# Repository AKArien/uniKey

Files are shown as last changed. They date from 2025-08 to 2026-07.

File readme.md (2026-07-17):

# Unikey

I think this name is corny as hell, but i needed one, sooo

Very unhappy with the way keyboards are currently handled (i’ll write my manifesto one day and i’ll link it here), this is my custom keyboard’s firmware, using the HID unicode page. It contains firmware source code and files i use to make the hardware, as well as examples to make your own.

# Hacking

If you want to change the layout for the unicode mode, check out src/key/unicode.h

If you want to tweak and re-use the usb reports, check out src/descriptors.h.

If you want a « classic » keyboard with one of the microcontrollers / physical builds (see below), you can change the code to force the mode and re-use it from there.

If you want a « classic » keyboard with another microncontroller / physical build, check out project [Golem](https://golem.hu/) and [QMK](https://github.com/qmk/qmk_firmware).

# Hardware

There is currently one physical keyboard in the project, though i do plan on making more.
The names used below are the ones needed for compilation of the firmware with them. Check firmware section for more details.

ALL_MAINBOARD :
- Physical configuration :
  - Ortholinear, 266\*95mm
  - Split, 2\*2,5-wide bottom-row keys « spacebar », 2-tall rightmost key « enter/return »
  - 5\*14,
- Available schematics use :
  - An arduino pro mini
  - 66 keys and as many diodes
  - Resistors and zener diodes for V-USB
- Features (almost) all the keys needed to make a classic keyboard, including « pinky keys » and arrow keys.
  - Lacks function keys, though you could probably easily add them to the topmost row (the keys that usually have numbers) with a modifier, or straight up adding a row of keys.
  - Doesn’t have space for both an escape and another key on the left of the topmost row (though most users probably wouldn’t even notice)
  - Assuming standard placement of return, backslash and modifiers, there is not really space for a classicly positioned « delete next » key. You could rather easily modify the pcb to make the « enter » key 1\*1, freeing space for another key and placing your deleting keys as you wish. The default is to have « delete previous » in the split long key on the bottom row and « delete next » in the top right corner.

# Firmware

The goal of the project is to make a keyboard that uses the Unicode HID page (0x10) for the host OS to use firmware-decided characters. In other words, a *really* plug and play keyboard.

As mentionned in hardware section, this repository will likely eventually have more keyboards. For now, only one exists.

Compilation of the firmware for the different models is scheduled to be handled with preprocessor flags passed to the makefile. So, to compile for the model ALL_MAINBOARD, you would use : ```make MODEL=ALL_MAINBOARD```

The ALL_MAINBOARD design uses the V-USB library, as it doesn’t have a dedicated USB chip.

To upload, use ```make upload ISP=<your in-circuit serial programmer, as per avrdude>```

Tip : UNOs can serve as in-cuircuit programmers ! They are named `arduino` to avrdude. Check out :
- Wiring and explanations : https://docs.arduino.cc/built-in-examples/arduino-isp/ArduinoISP/
- Arduino sketch : https://gist.github.com/srmq/0217a2844a9d82a6913ff989472a98dd

# Thanks

Obdev, for making V-USB

Sine Lab’s V-USB keyboard sample project, from which most of the code to use v-usb comes https://www.youtube.com/watch?v=6U_bHTnFu-g

The Kicad community, for making such good software and resources

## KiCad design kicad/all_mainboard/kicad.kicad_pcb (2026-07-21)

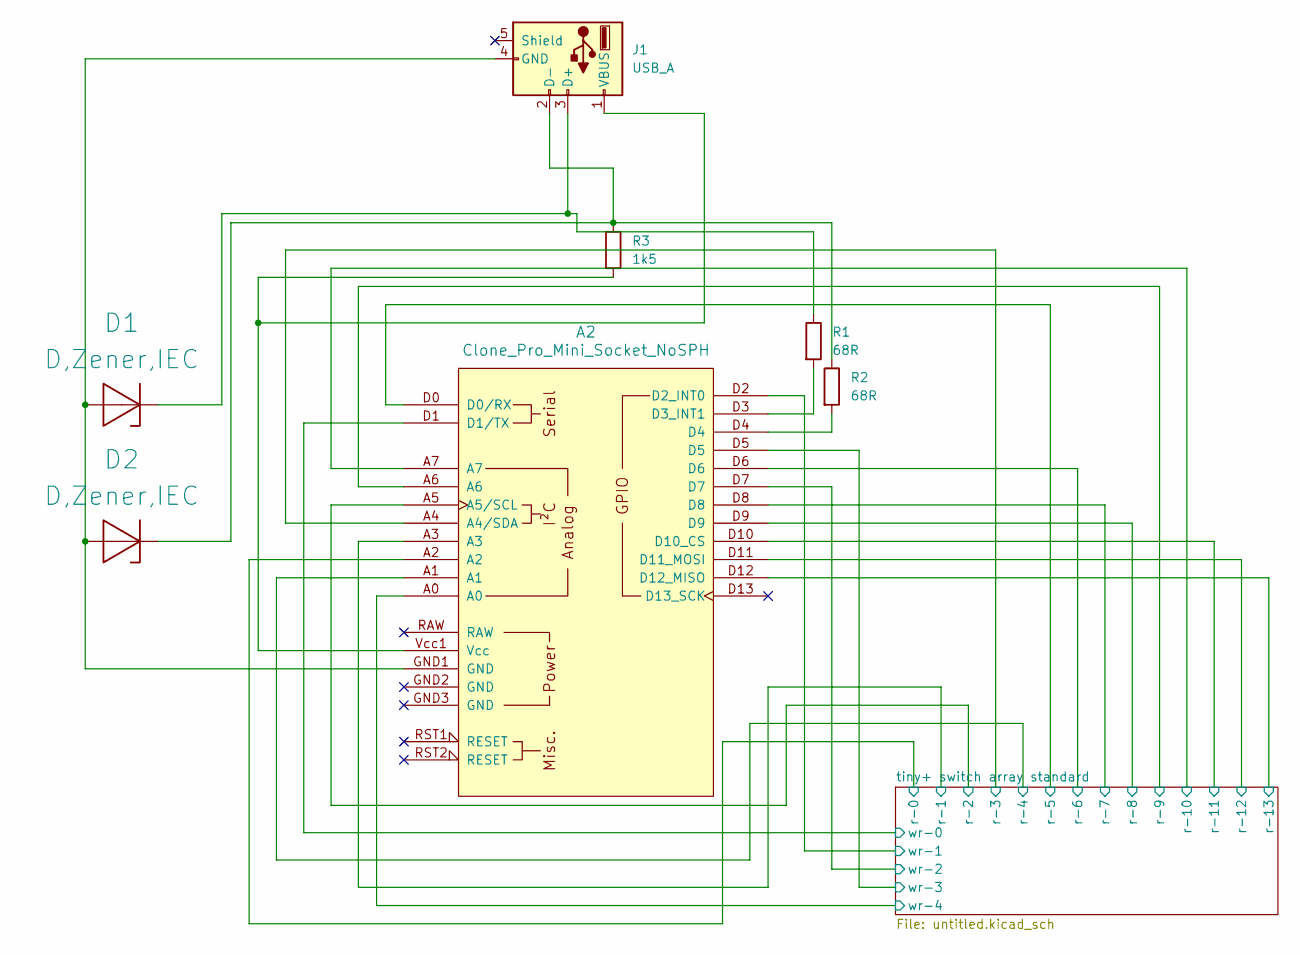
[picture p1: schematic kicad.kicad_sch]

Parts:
A2: Clone_Pro_Mini_Socket_NoSPH
D1, D2: D,Zener,IEC; D_DO-41_SOD81_P10.16mm_Horizontal
J1: USB_A; PinHeader_1x04_P2.00mm_Horizontal
R1, R2: 68R; D_DO-41_SOD81_P10.16mm_Horizontal
R3: 1k5; D_DO-41_SOD81_P10.16mm_Horizontal

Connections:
/tiny+ switch array standard/r-0: A2.A2; also elsewhere on the board
/tiny+ switch array standard/r-1: A2.A3; also elsewhere on the board
/tiny+ switch array standard/r-2: A2.A5 (A5/SCL); also elsewhere on the board
/tiny+ switch array standard/r-3: A2.A4 (A4/SDA); also elsewhere on the board
/tiny+ switch array standard/r-4: A2.A1; also elsewhere on the board
/tiny+ switch array standard/r-5: A2.D0 (D0/RX); also elsewhere on the board
/tiny+ switch array standard/r-6: A2.D6; also elsewhere on the board
/tiny+ switch array standard/r-7: A2.D8; also elsewhere on the board
/tiny+ switch array standard/r-8: A2.D9; also elsewhere on the board
/tiny+ switch array standard/r-9: A2.A6; also elsewhere on the board
/tiny+ switch array standard/r-10: A2.A7; also elsewhere on the board
/tiny+ switch array standard/r-11: A2.D10 (D10_CS); also elsewhere on the board
/tiny+ switch array standard/r-12: A2.D11 (D11_MOSI); also elsewhere on the board
/tiny+ switch array standard/r-13: A2.D12 (D12_MISO); also elsewhere on the board
/tiny+ switch array standard/wr-0: A2.D1 (D1/TX); also elsewhere on the board
/tiny+ switch array standard/wr-1: A2.D2 (D2_INT0); also elsewhere on the board
/tiny+ switch array standard/wr-2: A2.D7; also elsewhere on the board
/tiny+ switch array standard/wr-3: A2.D5; also elsewhere on the board
/tiny+ switch array standard/wr-4: A2.A0; also elsewhere on the board
unnamed: A2.D3 (D3_INT1), R1.2
unnamed: A2.D4, R2.2
unnamed: A2.Vcc1 (Vcc), J1.1 (VBUS), R3.2
unnamed: A2.GND1 (GND), D1.2 (A+), D2.2 (A+), J1.4 (GND)
unnamed: D1.1 (K-), J1.3 (D+), R1.1
unnamed: D2.1 (K-), J1.2 (D-), R2.1, R3.1

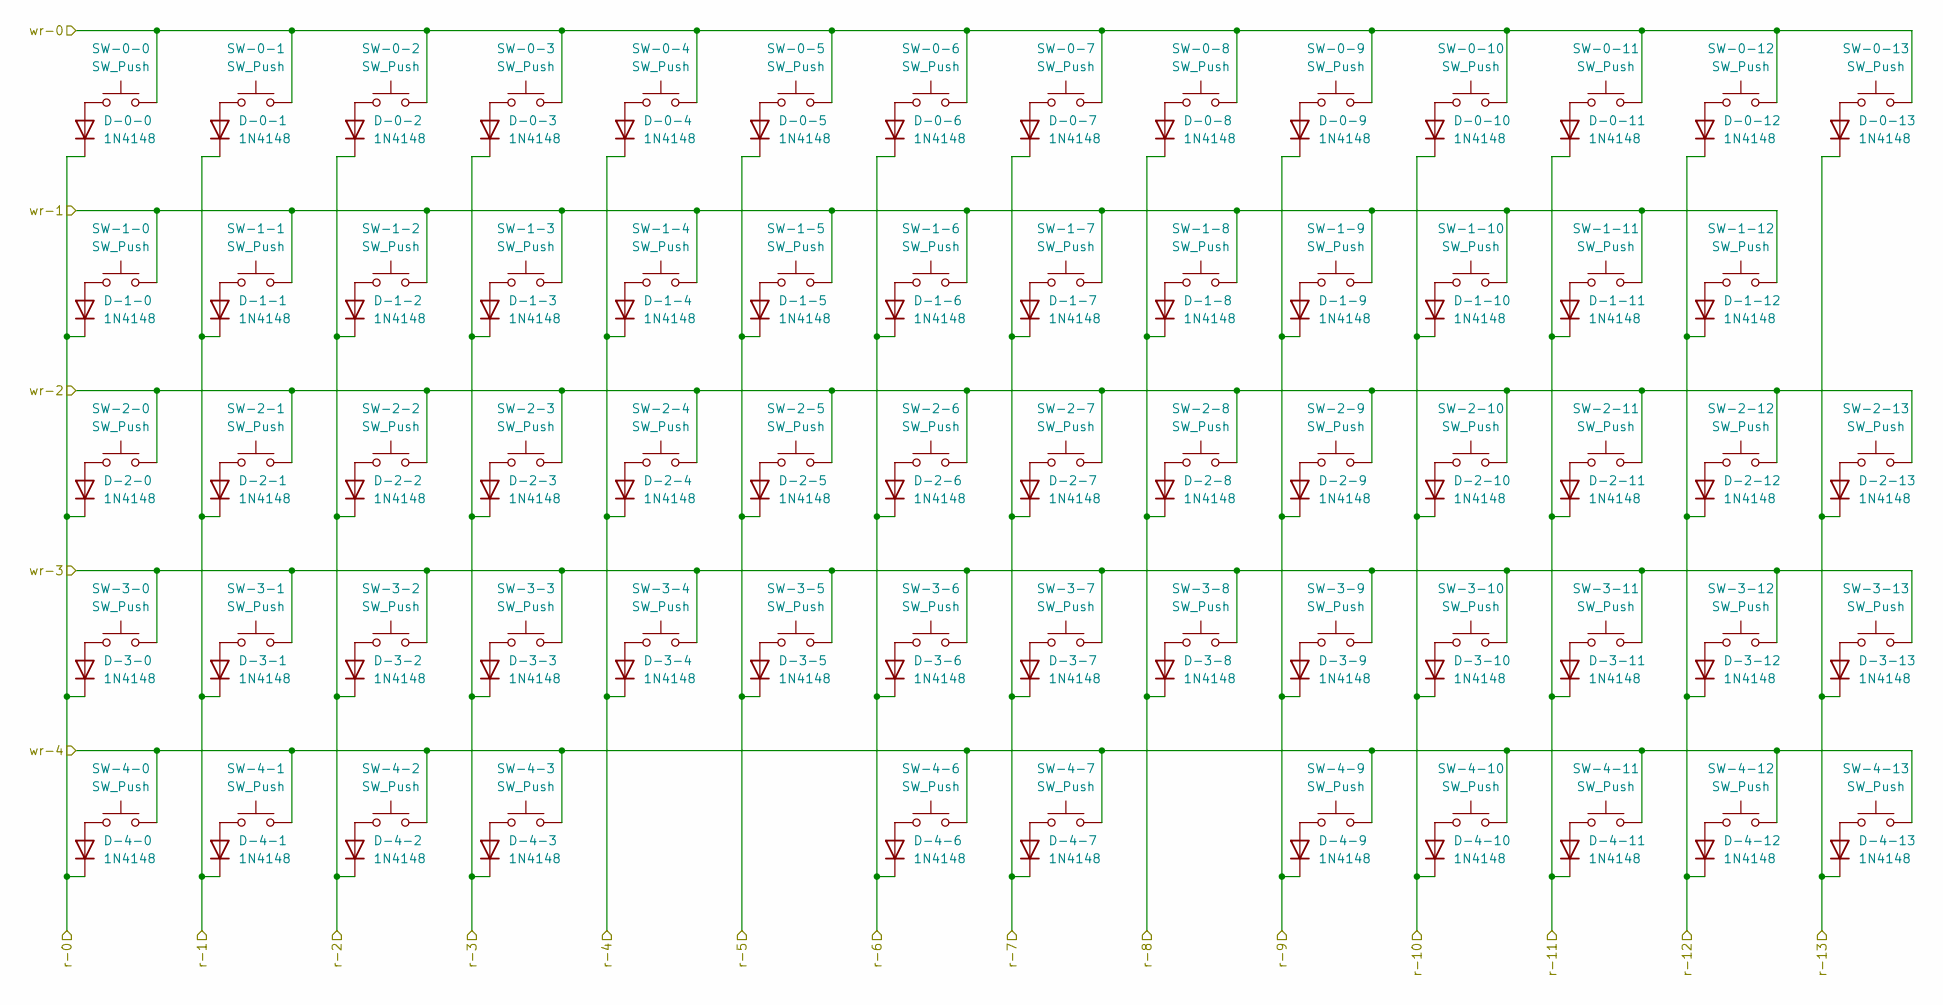
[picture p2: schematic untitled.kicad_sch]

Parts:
D-0-0, D-0-1, D-0-2, D-0-3, D-0-4, D-0-5, D-0-6, D-0-7, D-0-8, D-0-9, D-0-10, D-0-11, D-0-12, D-0-13, D-1-0, D-1-1, D-1-2, D-1-3, D-1-4, D-1-5, D-1-6, D-1-7, D-1-8, D-1-9, D-1-10, D-1-11, D-1-12, D-2-0, D-2-1, D-2-2, D-2-3, D-2-4, D-2-5, D-2-6, D-2-7, D-2-8, D-2-9, D-2-10, D-2-11, D-2-12, D-2-13, D-3-0, D-3-1, D-3-2, D-3-3, D-3-4, D-3-5, D-3-6, D-3-7, D-3-8, D-3-9, D-3-10, D-3-11, D-3-12, D-3-13, D-4-0, D-4-1, D-4-2, D-4-3, D-4-6, D-4-7, D-4-9, D-4-10, D-4-11, D-4-12, D-4-13: 1N4148; D_DO-35_SOD27_P7.62mm_Horizontal
SW-0-0, SW-0-1, SW-0-2, SW-0-3, SW-0-4, SW-0-5, SW-0-6, SW-0-7, SW-0-8, SW-0-9, SW-0-10, SW-0-11, SW-0-12, SW-0-13, SW-1-0, SW-1-1, SW-1-2, SW-1-3, SW-1-4, SW-1-5, SW-1-6, SW-1-7, SW-1-8, SW-1-9, SW-1-10, SW-1-11, SW-1-12, SW-2-0, SW-2-1, SW-2-2, SW-2-3, SW-2-4, SW-2-5, SW-2-6, SW-2-7, SW-2-8, SW-2-9, SW-2-10, SW-2-11, SW-2-12, SW-2-13, SW-3-0, SW-3-1, SW-3-2, SW-3-3, SW-3-4, SW-3-5, SW-3-6, SW-3-7, SW-3-8, SW-3-9, SW-3-10, SW-3-11, SW-3-12, SW-3-13, SW-4-0, SW-4-1, SW-4-2, SW-4-3, SW-4-6, SW-4-7, SW-4-9, SW-4-10, SW-4-11, SW-4-12, SW-4-13: SW_Push; SW_Cherry_MX_1.00u_PCB

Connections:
/tiny+ switch array standard/r-0: D-0-0.1 (K), D-1-0.1 (K), D-2-0.1 (K), D-3-0.1 (K), D-4-0.1 (K); also elsewhere on the board
/tiny+ switch array standard/r-1: D-0-1.1 (K), D-1-1.1 (K), D-2-1.1 (K), D-3-1.1 (K), D-4-1.1 (K); also elsewhere on the board
/tiny+ switch array standard/r-2: D-0-2.1 (K), D-1-2.1 (K), D-2-2.1 (K), D-3-2.1 (K), D-4-2.1 (K); also elsewhere on the board
/tiny+ switch array standard/r-3: D-0-3.1 (K), D-1-3.1 (K), D-2-3.1 (K), D-3-3.1 (K), D-4-3.1 (K); also elsewhere on the board
/tiny+ switch array standard/r-4: D-0-4.1 (K), D-1-4.1 (K), D-2-4.1 (K), D-3-4.1 (K); also elsewhere on the board
/tiny+ switch array standard/r-5: D-0-5.1 (K), D-1-5.1 (K), D-2-5.1 (K), D-3-5.1 (K); also elsewhere on the board
/tiny+ switch array standard/r-6: D-0-6.1 (K), D-1-6.1 (K), D-2-6.1 (K), D-3-6.1 (K), D-4-6.1 (K); also elsewhere on the board
/tiny+ switch array standard/r-7: D-0-7.1 (K), D-1-7.1 (K), D-2-7.1 (K), D-3-7.1 (K), D-4-7.1 (K); also elsewhere on the board
/tiny+ switch array standard/r-8: D-0-8.1 (K), D-1-8.1 (K), D-2-8.1 (K), D-3-8.1 (K); also elsewhere on the board
/tiny+ switch array standard/r-9: D-0-9.1 (K), D-1-9.1 (K), D-2-9.1 (K), D-3-9.1 (K), D-4-9.1 (K); also elsewhere on the board
/tiny+ switch array standard/r-10: D-0-10.1 (K), D-1-10.1 (K), D-2-10.1 (K), D-3-10.1 (K), D-4-10.1 (K); also elsewhere on the board
/tiny+ switch array standard/r-11: D-0-11.1 (K), D-1-11.1 (K), D-2-11.1 (K), D-3-11.1 (K), D-4-11.1 (K); also elsewhere on the board
/tiny+ switch array standard/r-12: D-0-12.1 (K), D-1-12.1 (K), D-2-12.1 (K), D-3-12.1 (K), D-4-12.1 (K); also elsewhere on the board
/tiny+ switch array standard/r-13: D-0-13.1 (K), D-2-13.1 (K), D-3-13.1 (K), D-4-13.1 (K); also elsewhere on the board
/tiny+ switch array standard/wr-0: SW-0-0.2, SW-0-1.2, SW-0-2.2, SW-0-3.2, SW-0-4.2, SW-0-5.2, SW-0-6.2, SW-0-7.2, SW-0-8.2, SW-0-9.2, SW-0-10.2, SW-0-11.2, SW-0-12.2, SW-0-13.2; also elsewhere on the board
/tiny+ switch array standard/wr-1: SW-1-0.2, SW-1-1.2, SW-1-2.2, SW-1-3.2, SW-1-4.2, SW-1-5.2, SW-1-6.2, SW-1-7.2, SW-1-8.2, SW-1-9.2, SW-1-10.2, SW-1-11.2, SW-1-12.2; also elsewhere on the board
/tiny+ switch array standard/wr-2: SW-2-0.2, SW-2-1.2, SW-2-2.2, SW-2-3.2, SW-2-4.2, SW-2-5.2, SW-2-6.2, SW-2-7.2, SW-2-8.2, SW-2-9.2, SW-2-10.2, SW-2-11.2, SW-2-12.2, SW-2-13.2; also elsewhere on the board
/tiny+ switch array standard/wr-3: SW-3-0.2, SW-3-1.2, SW-3-2.2, SW-3-3.2, SW-3-4.2, SW-3-5.2, SW-3-6.2, SW-3-7.2, SW-3-8.2, SW-3-9.2, SW-3-10.2, SW-3-11.2, SW-3-12.2, SW-3-13.2; also elsewhere on the board
/tiny+ switch array standard/wr-4: SW-4-0.2, SW-4-1.2, SW-4-2.2, SW-4-3.2, SW-4-6.2, SW-4-7.2, SW-4-9.2, SW-4-10.2, SW-4-11.2, SW-4-12.2, SW-4-13.2; also elsewhere on the board
unnamed: D-0-0.2 (A), SW-0-0.1
unnamed: D-0-1.2 (A), SW-0-1.1
unnamed: D-0-2.2 (A), SW-0-2.1
unnamed: D-0-3.2 (A), SW-0-3.1
unnamed: D-0-4.2 (A), SW-0-4.1
unnamed: D-0-5.2 (A), SW-0-5.1
unnamed: D-0-6.2 (A), SW-0-6.1
unnamed: D-0-7.2 (A), SW-0-7.1
unnamed: D-0-8.2 (A), SW-0-8.1
unnamed: D-0-9.2 (A), SW-0-9.1
unnamed: D-0-10.2 (A), SW-0-10.1
unnamed: D-0-11.2 (A), SW-0-11.1
unnamed: D-0-12.2 (A), SW-0-12.1
unnamed: D-0-13.2 (A), SW-0-13.1
unnamed: D-1-0.2 (A), SW-1-0.1
unnamed: D-1-1.2 (A), SW-1-1.1
unnamed: D-1-2.2 (A), SW-1-2.1
unnamed: D-1-3.2 (A), SW-1-3.1
unnamed: D-1-4.2 (A), SW-1-4.1
unnamed: D-1-5.2 (A), SW-1-5.1
unnamed: D-1-6.2 (A), SW-1-6.1
unnamed: D-1-7.2 (A), SW-1-7.1
unnamed: D-1-8.2 (A), SW-1-8.1
unnamed: D-1-9.2 (A), SW-1-9.1
unnamed: D-1-10.2 (A), SW-1-10.1
unnamed: D-1-11.2 (A), SW-1-11.1
unnamed: D-1-12.2 (A), SW-1-12.1
unnamed: D-2-0.2 (A), SW-2-0.1
unnamed: D-2-1.2 (A), SW-2-1.1
unnamed: D-2-2.2 (A), SW-2-2.1
unnamed: D-2-3.2 (A), SW-2-3.1
unnamed: D-2-4.2 (A), SW-2-4.1
unnamed: D-2-5.2 (A), SW-2-5.1
unnamed: D-2-6.2 (A), SW-2-6.1
unnamed: D-2-7.2 (A), SW-2-7.1
unnamed: D-2-8.2 (A), SW-2-8.1
unnamed: D-2-9.2 (A), SW-2-9.1
unnamed: D-2-10.2 (A), SW-2-10.1
unnamed: D-2-11.2 (A), SW-2-11.1
unnamed: D-2-12.2 (A), SW-2-12.1
unnamed: D-2-13.2 (A), SW-2-13.1
unnamed: D-3-0.2 (A), SW-3-0.1
unnamed: D-3-1.2 (A), SW-3-1.1
unnamed: D-3-2.2 (A), SW-3-2.1
unnamed: D-3-3.2 (A), SW-3-3.1
unnamed: D-3-4.2 (A), SW-3-4.1
unnamed: D-3-5.2 (A), SW-3-5.1
unnamed: D-3-6.2 (A), SW-3-6.1
unnamed: D-3-7.2 (A), SW-3-7.1
unnamed: D-3-8.2 (A), SW-3-8.1
unnamed: D-3-9.2 (A), SW-3-9.1
unnamed: D-3-10.2 (A), SW-3-10.1
unnamed: D-3-11.2 (A), SW-3-11.1
unnamed: D-3-12.2 (A), SW-3-12.1
unnamed: D-3-13.2 (A), SW-3-13.1
unnamed: D-4-0.2 (A), SW-4-0.1
unnamed: D-4-1.2 (A), SW-4-1.1
unnamed: D-4-2.2 (A), SW-4-2.1
unnamed: D-4-3.2 (A), SW-4-3.1
unnamed: D-4-6.2 (A), SW-4-6.1
unnamed: D-4-7.2 (A), SW-4-7.1
unnamed: D-4-9.2 (A), SW-4-9.1
unnamed: D-4-10.2 (A), SW-4-10.1
unnamed: D-4-11.2 (A), SW-4-11.1
unnamed: D-4-12.2 (A), SW-4-12.1
unnamed: D-4-13.2 (A), SW-4-13.1

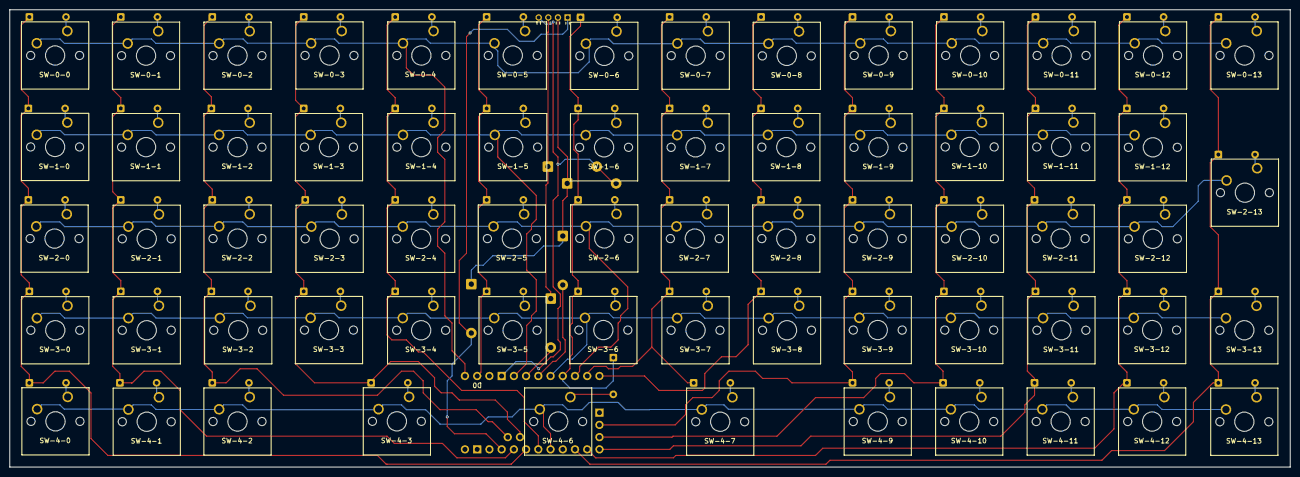
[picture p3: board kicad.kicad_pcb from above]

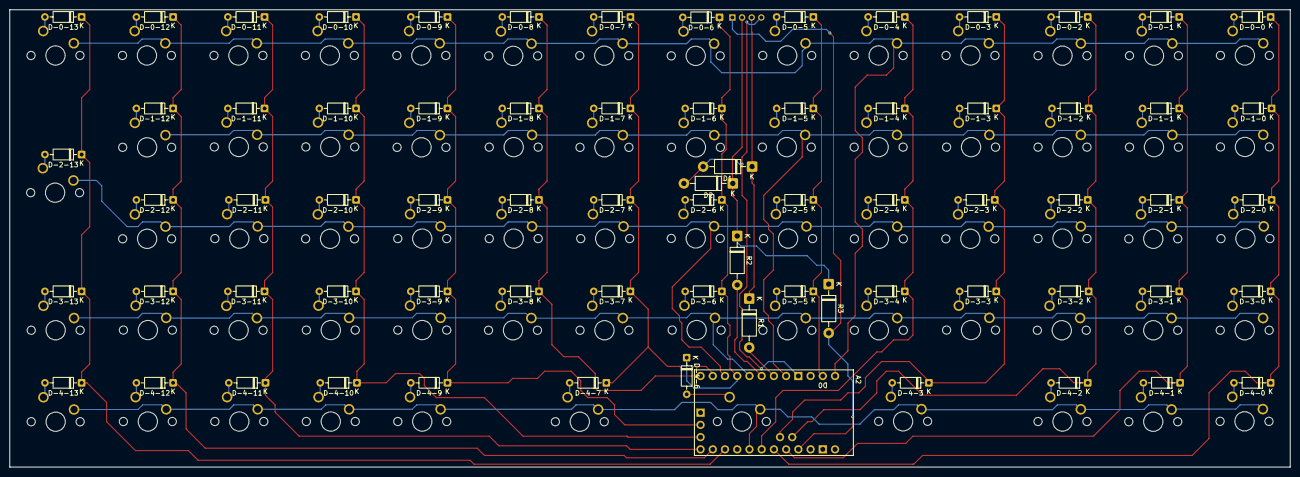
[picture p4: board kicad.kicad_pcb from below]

Board: 2 copper layers, 266.0 x 95.0 mm, 139 parts (72 on the bottom side), 91 nets.

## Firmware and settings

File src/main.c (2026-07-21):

#include <avr/io.h>
#include <avr/interrupt.h>
#include <avr/pgmspace.h>
#include <avr/wdt.h>
#include <util/delay.h>
#include <string.h>
#include <stdlib.h>

#include "v-usb/usbdrv/usbdrv.h"

#include "reportbuf.h"

int idle_rate = 500;

void init(){
#ifdef MODEL_ALL_MAINBOARD
	DDRB = 0x00;
	DDRC = 0x02;
	DDRD = 0xA6;
#endif
}

usbMsgLen_t usbFunctionSetup(uint8_t data[8]){
	usbRequest_t *rq = (void *) data;

	if((rq->bmRequestType & USBRQ_TYPE_MASK) == USBRQ_TYPE_MASK){
		switch(rq->bRequest){

			case USBRQ_HID_GET_REPORT:
				// Treat same as our interrupt IN (send keys)
				usbMsgPtr = (unsigned short)report_buffer;
				return sizeof(report_buffer);

			// Send or change Idle rate when commanded
			case USBRQ_HID_GET_IDLE:
				usbMsgPtr = (unsigned short)&idle_rate;
				return 1;

			case USBRQ_HID_SET_IDLE:
				idle_rate = rq->wValue.bytes[1];
				return 0;
		}
	}

	return 0;
}

int main(){

	init();

	set_mode(normal);

	// Watchdog, just in case
	wdt_enable(WDTO_1S);

	usbInit();
	// Re-enumerate device
	usbDeviceDisconnect();
	uchar i = 0;
	while(--i){
		wdt_reset();
		_delay_ms(1);
	}
	usbDeviceConnect();
	sei();

	for(;;){
		wdt_reset();

		usbPoll();

		// 0 is an indefinite idle
		if(idle_rate != 0) {
			for(int i = 0; i < idle_rate ; i++){
				_delay_ms(4);
			}
		}

		update_report_buffer();

		// Some fucker wants to know what happened
		if(usbInterruptIsReady()){
			// Send over the HID data
			usbSetInterrupt(report_buffer, sizeof(report_buffer));
		}

	return 0;
}

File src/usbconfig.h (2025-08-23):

/* Name: usbconfig.h
 * Project: V-USB, virtual USB port for Atmel's(r) AVR(r) microcontrollers
 * Author: Christian Starkjohann
 * Creation Date: 2005-04-01
 * Tabsize: 4
 * Copyright: (c) 2005 by OBJECTIVE DEVELOPMENT Software GmbH
 * License: GNU GPL v2 (see License.txt), GNU GPL v3 or proprietary (CommercialLicense.txt)
 */

#ifndef __usbconfig_h_included__
#define __usbconfig_h_included__

/*
General Description:
This file is an example configuration (with inline documentation) for the USB
driver. It configures V-USB for USB D+ connected to Port D bit 2 (which is
also hardware interrupt 0 on many devices) and USB D- to Port D bit 4. You may
wire the lines to any other port, as long as D+ is also wired to INT0 (or any
other hardware interrupt, as long as it is the highest level interrupt, see
section at the end of this file).
+ To create your own usbconfig.h file, copy this file to your project's
+ firmware source directory) and rename it to "usbconfig.h".
+ Then edit it accordingly.
*/

/* ---------------------------- Hardware Config ---------------------------- */

#define USB_CFG_IOPORTNAME      D
/* This is the port where the USB bus is connected. When you configure it to
 * "B", the registers PORTB, PINB and DDRB will be used.
 */
#define USB_CFG_DMINUS_BIT      4
/* This is the bit number in USB_CFG_IOPORT where the USB D- line is connected.
 * This may be any bit in the port.
 */
#define USB_CFG_DPLUS_BIT       3
/* This is the bit number in USB_CFG_IOPORT where the USB D+ line is connected.
 * This may be any bit in the port. Please note that D+ must also be connected
 * to interrupt pin INT0! [You can also use other interrupts, see section
 * "Optional MCU Description" below, or you can connect D- to the interrupt, as
 * it is required if you use the USB_COUNT_SOF feature. If you use D- for the
 * interrupt, the USB interrupt will also be triggered at Start-Of-Frame
 * markers every millisecond.]
 */
#define USB_CFG_CLOCK_KHZ       (F_CPU/1000)
/* Clock rate of the AVR in kHz. Legal values are 12000, 12800, 15000, 16000,
 * 16500, 18000 and 20000. The 12.8 MHz and 16.5 MHz versions of the code
 * require no crystal, they tolerate +/- 1% deviation from the nominal
 * frequency. All other rates require a precision of 2000 ppm and thus a
 * crystal!
 * Since F_CPU should be defined to your actual clock rate anyway, you should
 * not need to modify this setting.
 */
#define USB_CFG_CHECK_CRC       0
/* Define this to 1 if you want that the driver checks integrity of incoming
 * data packets (CRC checks). CRC checks cost quite a bit of code size and are
 * currently only available for 18 MHz crystal clock. You must choose
 * USB_CFG_CLOCK_KHZ = 18000 if you enable this option.
 */

/* ----------------------- Optional Hardware Config ------------------------ */

/* #define USB_CFG_PULLUP_IOPORTNAME   D */
/* If you connect the 1.5k pullup resistor from D- to a port pin instead of
 * V+, you can connect and disconnect the device from firmware by calling
 * the macros usbDeviceConnect() and usbDeviceDisconnect() (see usbdrv.h).
 * This constant defines the port on which the pullup resistor is connected.
 */
/* #define USB_CFG_PULLUP_BIT          4 */
/* This constant defines the bit number in USB_CFG_PULLUP_IOPORT (defined
 * above) where the 1.5k pullup resistor is connected. See description
 * above for details.
 */

/* --------------------------- Functional Range ---------------------------- */
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

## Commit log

2025-08-16 one less compilation error
    [main.c]
2025-08-18 fixed typo honestly i should do a 1984 because i don’t like where this is going
2025-08-21 clean schema with dirty pcb i probably should rewire everything would save 3 meters of copper wire
    [kicad.kicad_pcb, kicad.kicad_sch, matrix.sch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]
2025-08-24 updated (implemented lol) logic for getting which keys are currently pressed
2025-08-24 pins writes should be good if i didn’t logic too poorly ?
    [main.c]
2025-08-24 fixed errors and typos
    [main.c]
2025-08-24 corrected pins definitions and initialisation
    [main.c]
2025-08-26 added kicad files
    [kicad.kicad_pcb, kicad.kicad_sch, untitled.kicad_sch]
2025-09-20 slight update to pcb to cross at 90 degrees
    [kicad.kicad_pcb]
2025-10-05 minor pcb and schema updates
    [kicad.kicad_pcb, kicad.kicad_sch]
2025-10-05 (probably) final revision of all_mainboard pcb
2026-07-20 update pcb : move traces further from edges
    [kicad.kicad_pcb]
2026-07-21 further pcb tweaks
    [kicad.kicad_pcb]
